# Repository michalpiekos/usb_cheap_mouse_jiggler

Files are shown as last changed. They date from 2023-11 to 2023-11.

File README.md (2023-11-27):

# Cheap mouse jiggler on USB
Simple USB-HID Mouse device on: STM32F103 (bluepill), CH32V003 (10cent RiscV processor).

Idea is to find cheap microcontroller with minimum external components to build mouse jiggler. I am sure no one needs such comparison therefore... here it is. Aliexpress can do it for around 2-2.5$ for ready made USB dongle. I wonder if I can beat that price. I will calculate the price of finished product including PCB, all components like usb plug or socket, resistors, capacitors, crystals, power regulators and what have you. In case of complete boards the price will be the price. I do not calculate shipping costs and USB cable if needed.

1. <b>STM32F103</b> Bluepill<br>The cheapest one I found on aliexpress was for 1.94$ and the price of shipping was reasonable. Mouse jiggler is implemented using STM HAL and it is super easy, especially using CubeIDE or CubeMX environments. Cheap and popular bluepill is then the benchmark in this small test.

2. <b>CH32V003</b> the 0.10$ RiscV microcontroller<br> Already a strong contender. One would need to create its own PCB. I used slightly changed version of the one that cnlohr posted on his github: https://github.com/cnlohr/rv003usb. <br> 
<b>Pricing: </b>0.23$ for chip and that only when buying 50pcs, 0.62$ for PCB (at least that is my price at one of chinese manufacturers),  LDO was 0.04$ and I will add 0.12$ for capacitors and resistor and 0.08$ for USB male connector. That totals <b>1.09$</b>. <br>
Probably a winner at this point. 

## CH32V003 Schematics
Provided here is my early breadboard prototype and PCB which I have ordered at one of chinese manufacturers.<br>
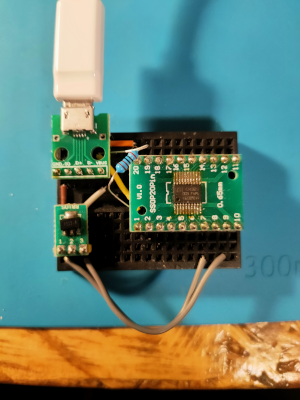
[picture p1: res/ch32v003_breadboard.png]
Breadboard prototype
 <br>
Prototype does work:<br>
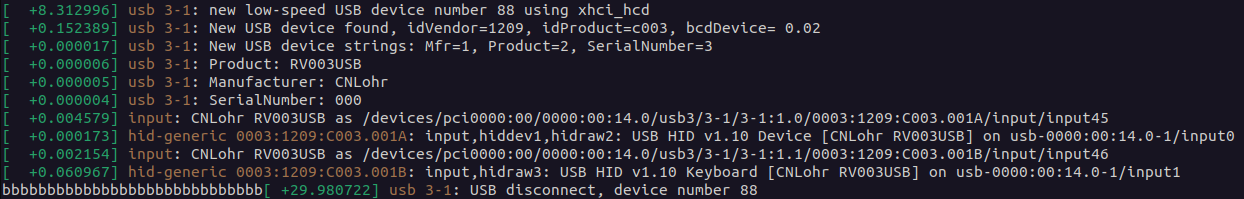
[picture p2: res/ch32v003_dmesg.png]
dmesg output
 <br>
PCB 3D view<br>
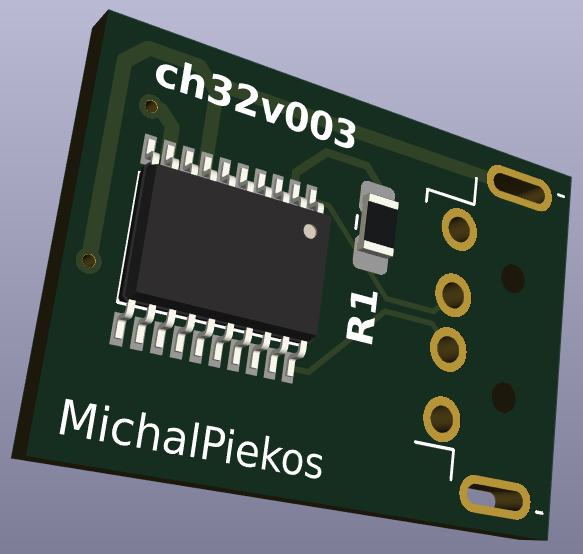
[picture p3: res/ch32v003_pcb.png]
PCB 3D View
 <br>

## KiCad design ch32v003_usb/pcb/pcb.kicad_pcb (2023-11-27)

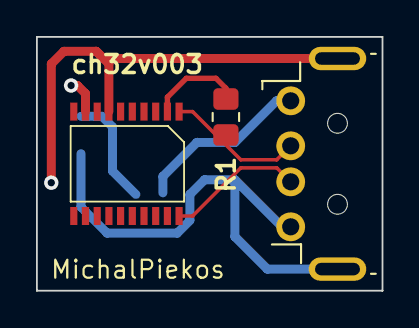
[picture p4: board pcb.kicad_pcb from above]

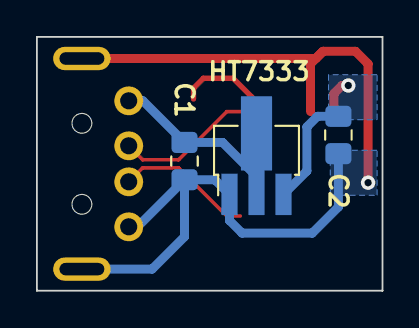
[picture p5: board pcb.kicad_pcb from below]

Board: 2 copper layers, 19.2 x 14.1 mm, 6 parts (3 on the bottom side), 6 nets.

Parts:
C1, C2: 10u; C_0805_2012Metric_Pad1.18x1.45mm_HandSolder
J1: USB_A; USB_A_Horizontal
R1: 1k5; R_0805_2012Metric_Pad1.20x1.40mm_HandSolder
U1: HT7333; SOT-89-3_Handsoldering
ch32v003f4p6: SSOP-20_4.4x6.5mm_P0.65mm

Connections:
+3.3V: C2.1, U1.3 (VOUT), ch32v003f4p6.9 (VDD)
+5V: C1.1, J1.1 (VBUS), U1.2 (VIN)
/DPU: R1.1, ch32v003f4p6.2 (PD5/A5/UTX/T2CH4_/URX_)
/USB_D+: J1.3 (D+), ch32v003f4p6.20 (PD3/A4/T2CH2/AETR/UCTS/T1CH4_)
/USB_D-: J1.2 (D-), R1.2, ch32v003f4p6.1 (PD4/A7/UCK/T2CH1ETR/OPO/T1CH4ETR_)
GND: C1.2, C2.2, J1.4 (GND), J1.5 (Shield), U1.1 (GND), ch32v003f4p6.7 (VSS)

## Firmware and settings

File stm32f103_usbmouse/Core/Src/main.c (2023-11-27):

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
/* Includes ------------------------------------------------------------------*/
#include "main.h"
#include "usb_device.h"

/* USER CODE BEGIN Includes */
#include "usbd_hid.h"
#include <math.h>
/* USER CODE END Includes */

/* USER CODE BEGIN PTD */
typedef struct {
  uint8_t button;
  int8_t mouse_x;
  int8_t mouse_y;
  int8_t wheel;
} typeMouseHID;
/* USER CODE END PTD */

/* USER CODE BEGIN PD */
#define RANGE                    100
/* USER CODE END PD */


/* USER CODE BEGIN PV */
extern USBD_HandleTypeDef hUsbDeviceFS;
typeMouseHID mousehid = {0, 0, 0, 0};
int16_t xCoordinate = -RANGE;
int8_t direction = 1;
/* USER CODE END PV */

void SystemClock_Config(void);
static void MX_GPIO_Init(void);
/**
  * @brief  The application entry point.
  * @retval int
  */
int main(void)
{
  /* MCU Configuration--------------------------------------------------------*/

  /* Reset of all peripherals, Initializes the Flash interface and the Systick. */
  HAL_Init();

  /* Configure the system clock */
  SystemClock_Config();

  /* Initialize all configured peripherals */
  MX_GPIO_Init();
  MX_USB_DEVICE_Init();
  /* Infinite loop */
  /* USER CODE BEGIN WHILE */
  while (1)
  {
    if ((xCoordinate < -RANGE) || (xCoordinate > RANGE)) {
      direction *= -1;
    }
    xCoordinate += direction;
    mousehid.mouse_x = direction;
    mousehid.mouse_y = direction;

    USBD_HID_SendReport(&hUsbDeviceFS, (uint8_t *)&mousehid, sizeof(mousehid));
    HAL_Delay(10);

    /* USER CODE END WHILE */

    /* USER CODE BEGIN 3 */
  }
  /* USER CODE END 3 */
}

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


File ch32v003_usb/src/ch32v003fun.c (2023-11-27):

// Mixture of embedlibc, and ch32v00x_startup.c



// Use with newlib headers.
// Mixture of weblibc, mini-printf and ???

#include <stdio.h>
#include <string.h>
#include <stdarg.h>
#include <limits.h>
#include <stdint.h>
#include "ch32v003fun.h"

int errno;

int mini_vsnprintf(char *buffer, unsigned int buffer_len, const char *fmt, va_list va);
int mini_vpprintf(int (*puts)(char* s, int len, void* buf), void* buf, const char *fmt, va_list va);

static int __puts_uart(char *s, int len, void *buf)
{
	_write( 0, s, len );
	return len;
}

int printf(const char* format, ...)
{
	va_list args;
	va_start( args, format );
	int ret_status = mini_vpprintf(__puts_uart, 0, format, args);
	va_end( args );
	return ret_status;
}
	
/* Some stuff from MUSL


----------------------------------------------------------------------
Copyright © 2005-2020 Rich Felker, et al.

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
THE SOFTWARE IS PROVIDED "AS IS", WITHOUT WARRANTY OF ANY KIND,
EXPRESS OR IMPLIED, INCLUDING BUT NOT LIMITED TO THE WARRANTIES OF
MERCHANTABILITY, FITNESS FOR A PARTICULAR PURPOSE AND NONINFRINGEMENT.
IN NO EVENT SHALL THE AUTHORS OR COPYRIGHT HOLDERS BE LIABLE FOR ANY
CLAIM, DAMAGES OR OTHER LIABILITY, WHETHER IN AN ACTION OF CONTRACT,
TORT OR OTHERWISE, ARISING FROM, OUT OF OR IN CONNECTION WITH THE
SOFTWARE OR THE USE OR OTHER DEALINGS IN THE SOFTWARE.
----------------------------------------------------------------------

*/

/*
 * mbstate_t is an opaque object to keep conversion state, during multibyte
 * stream conversions.  The content must not be referenced by user programs.
 */

#define CURRENT_UTF8 0
#define IS_CODEUNIT(c) ((unsigned)(c)-0xdf80 < 0x80)
#define MB_CUR_MAX (CURRENT_UTF8 ? 4 : 1)

typedef void * mbstate_t;

#ifdef UNICODE
size_t wcrtomb(char *restrict s, wchar_t wc, mbstate_t *restrict st)
{
	if (!s) return 1;
	if ((unsigned)wc < 0x80) {
		*s = wc;
		return 1;
	} else if (MB_CUR_MAX == 1) {
		if (!IS_CODEUNIT(wc)) {
			errno = 0x02; // EILSEQ
			return -1;
		}
		*s = wc;
		return 1;
	} else if ((unsigned)wc < 0x800) {
		*s++ = 0xc0 | (wc>>6);
		*s = 0x80 | (wc&0x3f);
		return 2;
	} else if ((unsigned)wc < 0xd800 || (unsigned)wc-0xe000 < 0x2000) {
		*s++ = 0xe0 | (wc>>12);
		*s++ = 0x80 | ((wc>>6)&0x3f);
		*s = 0x80 | (wc&0x3f);
		return 3;
	} else if ((unsigned)wc-0x10000 < 0x100000) {
		*s++ = 0xf0 | (wc>>18);
		*s++ = 0x80 | ((wc>>12)&0x3f);
		*s++ = 0x80 | ((wc>>6)&0x3f);
		*s = 0x80 | (wc&0x3f);
		return 4;
	}
	errno = 0x02;//EILSEQ;
	return -1;
}
int wctomb(char *s, wchar_t wc)
{
	if (!s) return 0;
	return wcrtomb(s, wc, 0);
}
#endif
size_t strlen(const char *s) { const char *a = s;for (; *s; s++);return s-a; }
size_t strnlen(const char *s, size_t n) { const char *p = memchr(s, 0, n); return p ? p-s : n;}
void *memset(void *dest, int c, size_t n) { unsigned char *s = dest; for (; n; n--, s++) *s = c; return dest; }
char *strcpy(char *d, const char *s) { for (; (*d=*s); s++, d++); return d; }
char *strncpy(char *d, const char *s, size_t n) { for (; n && (*d=*s); n--, s++, d++); return d; }
int strcmp(const char *l, const char *r)
{
	for (; *l==*r && *l; l++, r++);
	return *(unsigned char *)l - *(unsigned char *)r;
}
int strncmp(const char *_l, const char *_r, size_t n)
{
	const unsigned char *l=(void *)_l, *r=(void *)_r;
	if (!n--) return 0;
	for (; *l && *r && n && *l == *r ; l++, r++, n--);
	return *l - *r;
}

static char *twobyte_strstr(const unsigned char *h, const unsigned char *n)
{
	uint16_t nw = n[0]<<8 | n[1], hw = h[0]<<8 | h[1];
	for (h++; *h && hw != nw; hw = hw<<8 | *++h);
	return *h ? (char *)h-1 : 0;
}

static char *threebyte_strstr(const unsigned char *h, const unsigned char *n)
{
	uint32_t nw = (uint32_t)n[0]<<24 | n[1]<<16 | n[2]<<8;
	uint32_t hw = (uint32_t)h[0]<<24 | h[1]<<16 | h[2]<<8;
	for (h+=2; *h && hw != nw; hw = (hw|*++h)<<8);
	return *h ? (char *)h-2 : 0;
}

static char *fourbyte_strstr(const unsigned char *h, const unsigned char *n)
{
	uint32_t nw = (uint32_t)n[0]<<24 | n[1]<<16 | n[2]<<8 | n[3];
	uint32_t hw = (uint32_t)h[0]<<24 | h[1]<<16 | h[2]<<8 | h[3];
	for (h+=3; *h && hw != nw; hw = hw<<8 | *++h);
	return *h ? (char *)h-3 : 0;
}

#define MAX(a,b) ((a)>(b)?(a):(b))
#define MIN(a,b) ((a)<(b)?(a):(b))

#define BITOP(a,b,op) \
 ((a)[(size_t)(b)/(8*sizeof *(a))] op (size_t)1<<((size_t)(b)%(8*sizeof *(a))))

static char *twoway_strstr(const unsigned char *h, const unsigned char *n)
{
	const unsigned char *z;
	size_t l, ip, jp, k, p, ms, p0, mem, mem0;
	size_t byteset[32 / sizeof(size_t)] = { 0 };
	size_t shift[256];

	/* Computing length of needle and fill shift table */
	for (l=0; n[l] && h[l]; l++)
		BITOP(byteset, n[l], |=), shift[n[l]] = l+1;
	if (n[l]) return 0; /* hit the end of h */

	/* Compute maximal suffix */
	ip = -1; jp = 0; k = p = 1;
	while (jp+k<l) {
		if (n[ip+k] == n[jp+k]) {
			if (k == p) {
				jp += p;
				k = 1;
			} else k++;
		} else if (n[ip+k] > n[jp+k]) {
			jp += k;
			k = 1;
			p = jp - ip;
		} else {
			ip = jp++;
			k = p = 1;
		}
	}
	ms = ip;
	p0 = p;

	/* And with the opposite comparison */
	ip = -1; jp = 0; k = p = 1;
	while (jp+k<l) {
		if (n[ip+k] == n[jp+k]) {
			if (k == p) {
				jp += p;
				k = 1;
			} else k++;
		} else if (n[ip+k] < n[jp+k]) {
			jp += k;
			k = 1;
			p = jp - ip;
		} else {
			ip = jp++;
			k = p = 1;
		}
	}
	if (ip+1 > ms+1) ms = ip;
	else p = p0;

	/* Periodic needle? */
	if (memcmp(n, n+p, ms+1)) {
		mem0 = 0;
		p = MAX(ms, l-ms-1) + 1;
	} else mem0 = l-p;
	mem = 0;

	/* Initialize incremental end-of-haystack pointer */
	z = h;

	/* Search loop */
	for (;;) {
		/* Update incremental end-of-haystack pointer */
		if (z-h < l) {
			/* Fast estimate for MAX(l,63) */
			size_t grow = l | 63;
			const unsigned char *z2 = memchr(z, 0, grow);
			if (z2) {
				z = z2;
				if (z-h < l) return 0;
			} else z += grow;
		}

		/* Check last byte first; advance by shift on mismatch */
		if (BITOP(byteset, h[l-1], &)) {
			k = l-shift[h[l-1]];
			if (k) {
				if (k < mem) k = mem;
				h += k;
				mem = 0;
				continue;
			}
		} else {
			h += l;
			mem = 0;
			continue;
		}

		/* Compare right half */
		for (k=MAX(ms+1,mem); n[k] && n[k] == h[k]; k++);
		if (n[k]) {
			h += k-ms;
			mem = 0;
			continue;
		}
		/* Compare left half */
		for (k=ms+1; k>mem && n[k-1] == h[k-1]; k--);
		if (k <= mem) return (char *)h;
		h += p;
		mem = mem0;
	}
}

char *strstr(const char *h, const char *n)
{
	/* Return immediately on empty needle */
	if (!n[0]) return (char *)h;

	/* Use faster algorithms for short needles */
	h = strchr(h, *n);
	if (!h || !n[1]) return (char *)h;
	if (!h[1]) return 0;
	if (!n[2]) return twobyte_strstr((void *)h, (void *)n);
	if (!h[2]) return 0;
	if (!n[3]) return threebyte_strstr((void *)h, (void *)n);
	if (!h[3]) return 0;
	if (!n[4]) return fourbyte_strstr((void *)h, (void *)n);

	return twoway_strstr((void *)h, (void *)n);
}
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

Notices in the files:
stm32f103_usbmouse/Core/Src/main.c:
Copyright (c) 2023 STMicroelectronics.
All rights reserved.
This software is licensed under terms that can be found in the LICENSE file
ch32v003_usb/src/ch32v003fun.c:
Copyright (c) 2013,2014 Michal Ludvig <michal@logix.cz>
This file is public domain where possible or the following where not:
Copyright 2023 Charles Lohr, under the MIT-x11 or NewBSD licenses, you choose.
